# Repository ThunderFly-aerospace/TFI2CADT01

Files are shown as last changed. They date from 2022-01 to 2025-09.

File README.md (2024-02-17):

# TFI2CADT01 - I²C address translator

TFI2CADT01 is an I2C device address changer. This function allows you to connect multiple I2C devices with the same address to one master device on the same bus.

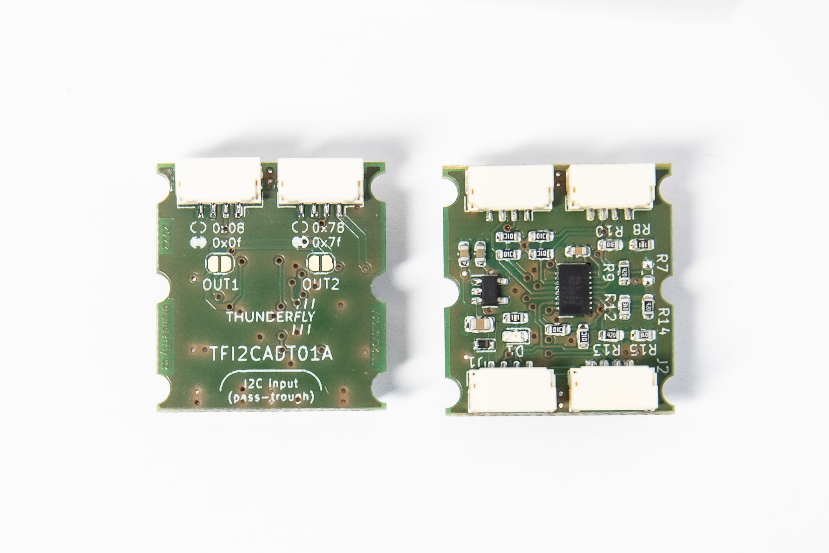
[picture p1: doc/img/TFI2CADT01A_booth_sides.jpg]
TFI2CADT01A PCB design


That is a common problem in case multiple I2C sensors with the same address (or a limited number of addresses) need to be connected to one I2C master. The purpose of this module is to change the address with which the I2C master calls to the address of the target I2C (slave) device.
The module is based on [LTC4317](https://www.analog.com/media/en/technical-documentation/data-sheets/4317fa.pdf) I2C address translator IC.
The module is designed and optimized for use on Pixhawk-compatible drones, especially UAVs. The design of the module is compatible with the [dronecode connectors standard](https://github.com/pixhawk/Pixhawk-Standards/blob/master/DS-009%20Pixhawk%20Connector%20Standard.pdf).

## Where to get it?

ThunderFly I2C address translator is commercially available from [ThunderFly s.r.o.](https://www.thunderfly.cz/), write an email to info@thunderfly.cz or shop at [Tindie store](https://www.tindie.com/products/thunderfly/tfi2cadt01-i2c-address-translator/).

## Translation function

The called address of the slave device is translated by a logical operation [XOR](https://en.wikipedia.org/wiki/Bitwise_operation#XOR) with the address bits configured in the TFI2CADT01 module. Each TFI2CADT01 port has a different default address. The address of each port can be changed independently by soldering solder jumpers JP1 and JP2.

NOTE: The TFI2CADT01 is not an I2C buffer, therefore the quality of input bits affects its function, and also corrupted data on input are propagated on the output. The address translator does XOR with the input address clocked in. To avoid related issues with bus data integrity we strongly recommend using ThunderFly's [TFCABI2C cables](https://github.com/ThunderFly-aerospace/TFCAB01) which minimizes SDA/SCL crosstalks. In some cases, where the I2C network has a significant length or number of nodes the use of [TFI2CEXT01](https://github.com/ThunderFly-aerospace/TFI2CEXT01), that is I2C extender with buffer function. 

## Configuration

The default address translation is listed in the following table.

| Port | Solder jumper | XOR value (in hex) | XOR value in binary form |
|---|---|---|---|
| 1 | Disconnected (default) | 0x08 | 0b0001000 |
| 1 | Soldered | 0x0f | 0b0001111 |
| 2 | Disconnected (default) | 0x78 | 0b1111000 |
| 2 | Soldered | 0x7f | 0b1111111 |

The connectors on the top side and the unpopulated connector on the bottom side are identical. There is no address difference between them. That should be used to split the bus to other sensors.

### Determining the new address of the I2C device

The new device address which should be called by the master could be calculated by doing XOR with the TFI2CADT01 port address and original device address.  The result is the new device address. You can use an [online calculator](https://xor.pw/) to do that. Another approach is determining the new address heuristically by use of the `i2cdetect` command or similar. 

## Example of usage

The TFI2CADT01 could be used with a wide variety of ThunderFly or Pixhawk I²C sensors, here are a few examples.

### Tachometer (RPM) sensors

The TFI2CADT01 could be easily used for the connection of multiple [TFRPM01 tachometer](https://github.com/ThunderFly-aerospace/TFRPM01) sensors, which is especially useful for multi-rotor airframes.

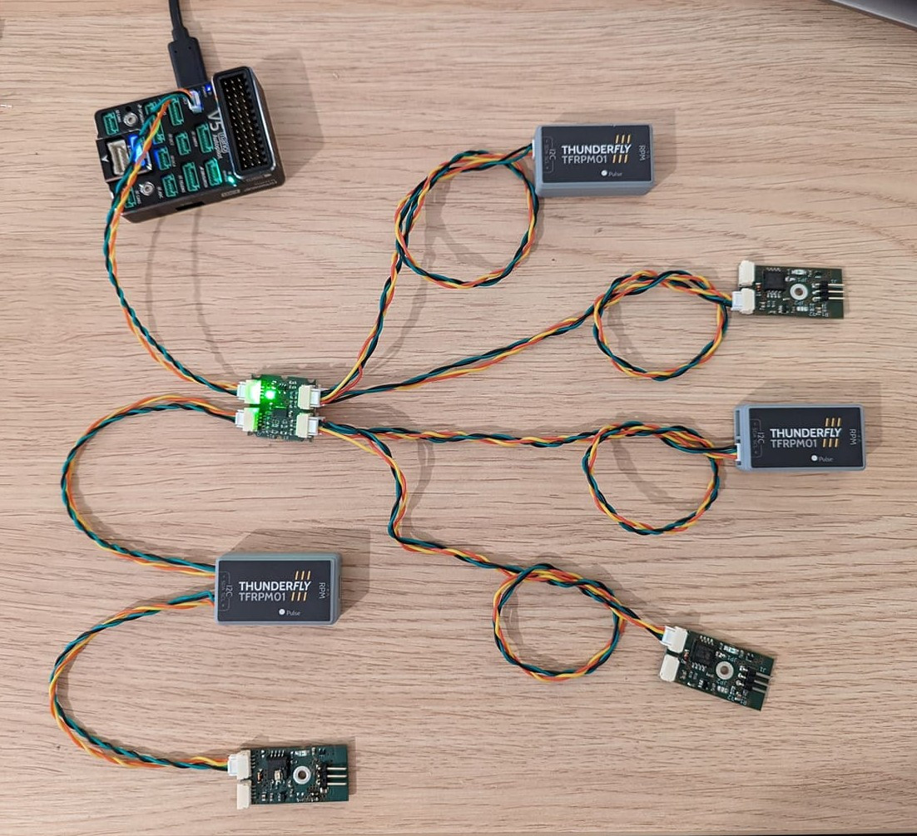
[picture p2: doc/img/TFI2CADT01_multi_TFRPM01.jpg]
TFI2CADT01A using multiple TFRPM01 sensors


### Redundant airspeed sensors

The TFI2CADT01 could also fix troubles with the connection of multiple [TFSLOT01 airspeed sensors](https://github.com/ThunderFly-aerospace/TFSLOT01) to one bus. It could be used even for other I2C-based airspeed sensors. That could increase the redundancy, in situations where a failure of the sensor is more probable than failure of the bus itself.

TFSLOT airspeed sensor

### Temperature and hygrometer sensors

For example the [TFHT01](https://github.com/ThunderFly-aerospace/TFHT01) connected by use of TFI2CADT01 allows measuring of temperature and humidity by multiple airframe locations at once.

TFHT01

## FAQ

### How I can change the I2C addresses used in the Pixhawk to the ones translated by the TFI2CADT01?

The translated addresses might not be recognized by default in the PX4 (that is usually experienced in the case of the SDP3x sensor driver).
One approach to solve that is to create a configuration file named `config.txt` on the SD card as is documented in the [PX4 documentation](https://docs.px4.io/main/en/concept/system_startup.html#replacing-the-system-startup). In this file, you can specify the start commands for the driver of the translated sensors.

Here's an example of the content of the `/etc/config.txt` on the SD card:

```
sdp3x_airspeed start -X -a <translated_address_a>
sdp3x_airspeed start -X -a <translated_address_b>
```

Replace `<translated_address_a>` and `<translated_address_b>` with the actual translated I2C addresses of your sensors. Addresses could be obtained by calculating XOR with the original address. Or it can be obtained with the `i2cdetect` command.

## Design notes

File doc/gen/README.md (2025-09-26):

# PCB

Board size: 25.0x23.0 mm (0.98x0.91 inches)

- This is the size of the rectangle that contains the board
- Thickness: 1.6 mm (63 mils)
- Material: FR4
- Finish: None
- Layers: 2
- Copper thickness: 35 µm

Solder mask: TOP / BOTTOM

- Color: Green

Silk screen: TOP / BOTTOM

- Color: White

Stackup:

| Name | Type | Color | Thickness [µm]| Material | Er | Loss tan |
|---|---|---|---|---|---|---|
| F.SilkS | Top Silk Screen | | | | | |
| F.Paste | Top Solder Paste | | | | | |
| F.Mask | Top Solder Mask | Green | 10 | | | |
| F.Cu | copper | | 35 | | | |
| dielectric 1 | core | | 1510 | FR4 | 4.5 | 0.020 |
| B.Cu | copper | | 35 | | | |
| B.Mask | Bottom Solder Mask | Green | 10 | | | |
| B.Paste | Bottom Solder Paste  | | | | | |
| B.SilkS | Bottom Silk Screen | | | | | |

# Important sizes

Clearance: 0.2 mm (8 mils)

Track width: 0.2 mm (8 mils)

- By design rules: 0.2 mm (8 mils)

Drill: 0.5 mm (20 mils)

- Vias: 0.5 mm (20 mils) [Design: 0.4 mm (16 mils)]
- Pads: 3.0 mm (118 mils)
- The above values are real drill sizes, they add 0.1 mm (4 mils) to plated holes (PTH)

Via: 0.8/0.4 mm (31/16 mils)

- By design rules: 0.4/0.3 mm (16/12 mils)
- Micro via: yes [0.2/0.1 mm (8/4 mils)]
- Buried/blind via: yes
- Total: 49 (thru: 49 buried/blind: 0 micro: 0)

Outer Annular Ring: 0.15 mm (6 mils)

- By design rules: N/A mm (N/A mils)

Eurocircuits class: 4B
- Using min drill 0.5 mm for an OAR of 0.15 mm

# General stats

Components count: (SMD/THT)

- Top: 2/6 (SMD + THT)
- Bottom: 27/0 (SMD)

Defined tracks:

- 0.2 mm (8 mils)
- 0.3 mm (12 mils)
- 0.4 mm (16 mils)
- 0.5 mm (20 mils)
- 0.6 mm (24 mils)

Used tracks:

- 0.2 mm (8 mils) (155) defined: yes
- 0.25 mm (10 mils) (20) defined: no
- 0.5 mm (20 mils) (73) defined: yes

Defined vias:

Used vias:

- 0.8/0.4 mm (31/16 mils) (Count: 49, Aspect: 2.0 A) defined: no

Holes (excluding vias):

- 3.0 mm (118 mils) (6)

Oval holes:

Drill tools (including vias and computing adjusts and rounding):

- 0.5 mm (20 mils) (49)
- 3.0 mm (118 mils) (6)

Solder paste stats:

Using a paste with 87.75 % alloy, that has an specific gravity for the alloy of 7.4 g/cm³
and 1.0 g/cm³ for the flux. This paste has an specific gravity of  4.15 g/cm³.

The stencil thickness is  0.12 mm.

| Side | Pads with paste | Area [mm²] | Paste [g] |
|---|---|---|---|
| Top | 12 | 18.56 | 0.09 |
| Bottom | 97 | 80.05 | 0.40 |
| Total  | 109 | 98.61 | 0.49 |

Note: this is just an approximation to the theoretical value. Margins of the solder mask and waste aren't computed.

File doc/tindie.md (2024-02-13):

### What is it?
TFI2CADT is a device translating addresses of I2C devices on a bus. As a result, multiple I2C slave devices with the same address can be connected to one master device. One TFI2CADT01 allows connecting 3 identical I2C devices (with one address) to one bus. The I2C slave device will be visible under three addresses. 

The module is designed in accordance with the [pixhawk connector dronecode](https://github.com/pixhawk/Pixhawk-Standards/blob/master/DS-009%20Pixhawk%20Connector%20Standard.pdf) standard. Thanks to this, it can be very easily implemented into the existing avionics of your drone.

### Why did we make it?
It often happens that more identical I2C devices (with the same address) need to be connected to one bus. We even had a request for connecting 4-8 RPM tachometers [TFRPM01](https://www.tindie.com/products/thunderfly/tfrpm01-drone-rpm-tachometer-sensor/) to PX4 autopilot.

### What makes it special?
The device is unique in that the address translation takes place in real-time, during communication via I2C. The user software does not have to deal with any multiplexer channels switching or disconnecting individual parts of the bus. This feature also solves the amount of data flow on the bus. All devices are constantly visible for the I2C master device.

###  How does the translation work?
The address translation takes place internally. A logical operation XOR with a preset value is applied to the address sent by the master. The XOR value is different for each channel. 

By default, an XOR value of 0x08 is applied on the first port and a value of 0x78 on the second port. These values can be easily changed to 0x0f and 0x7f respectively, by short-circuiting the solder jumper.

If these changes are still not sufficient, using configuration resistors you can create any XOR translation of the original address of the device. More information about the address change can be found in the datasheet.

###  How do I connect with the translator? 
Connecting the translator is simple. It is just placed between the I2C master and I2C slave devices. TFI2CADT has JST-GH connectors whose connection corresponds to the dronecode standard. 

Using an adequate cable, the translator can be connected to e.g. Arduino, raspberry, or other devices using I2C. The board is equipped with a pair of input ports that are internally interconnected to enable daisy-chain topology.

### How is the translator supported? 

The translator does not need a software configuration and from the point of view of I2C communication is not visible. Thanks to this, it can be used with any I2C bus, therefore it could be used with any Pixhawk autopilot compatible firmware like [PX4](https://px4.io/) or [Ardupilot](https://ardupilot.org/) additionally the usage is not limited to UAVs only.

### What’s included?

- 1x TFI2CADT01B
- Optionally: 
   - [TFCABxxI2C01](https://github.com/ThunderFly-aerospace/TFCAB01) Silicone I2C cable with JST-GH connectors

### Accessories

#### I2C cabling 
Additional I2C cables for connecting to the autopilot are not included in the package. You must purchase the additional cables separately from our [tindie catalog](https://www.tindie.com/stores/thunderfly/). We offer high-quality cables that are compatible with the [Pixhawk standard](https://raw.githubusercontent.com/pixhawk/Pixhawk-Standards/master/DS-009%20Pixhawk%20Connector%20Standard.pdf) and with a [ThunderFly color](https://docs.px4.io/main/en/assembly/cable_wiring.html#i2c-cables) scheme for easy signal identification. Our cables are specifically designed with improved resistance to electromagnetic interference and a silicone insulator that makes them highly flexible.

  * [TFCABxxI2C01 products](https://www.tindie.com/products/30113/)

# Product changelog
The product is gradually evolving and improving based on user requirements. Currently (as of 02/2024), the TFI2CADT01B revision is being shipped. In the development process, we keep backward compatibility, for example by keeping the same form factor or communication interface. The complete list of changes is in [releases](https://github.com/ThunderFly-aerospace/TFI2CADT01/releases).
 
#### TFI2CADT01B - (from 2/2024)
 * JST-GH connectors moved slightly into the PCB contour to enhance the protection of the connector and improve soldering quality.

#### TFI2CADT01A - initial version

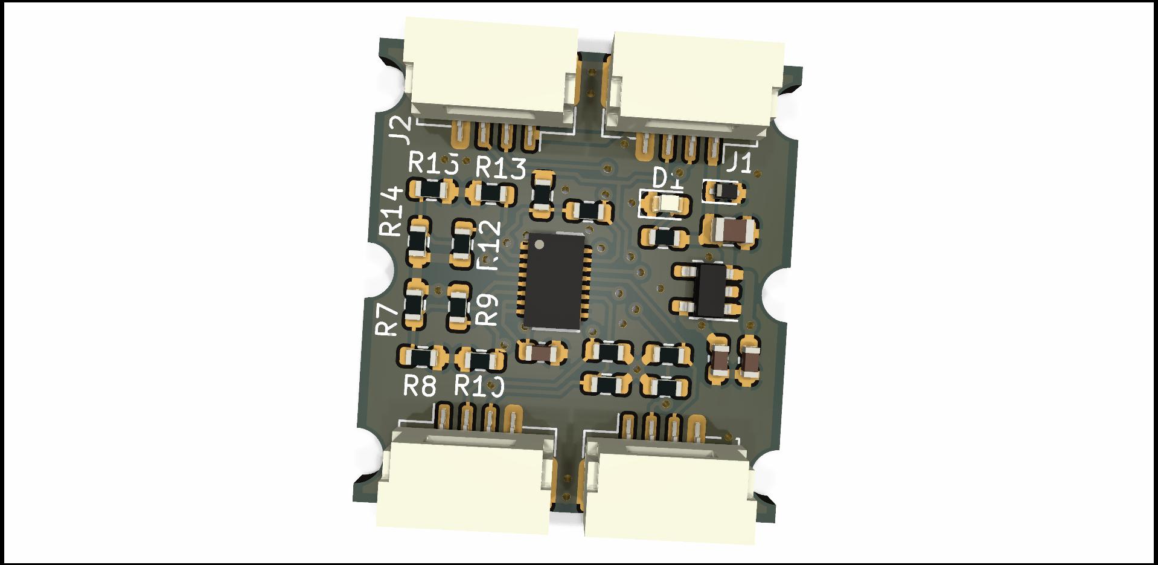
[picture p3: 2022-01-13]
doc/img/TFI2CADT01A_big_bot.jpg

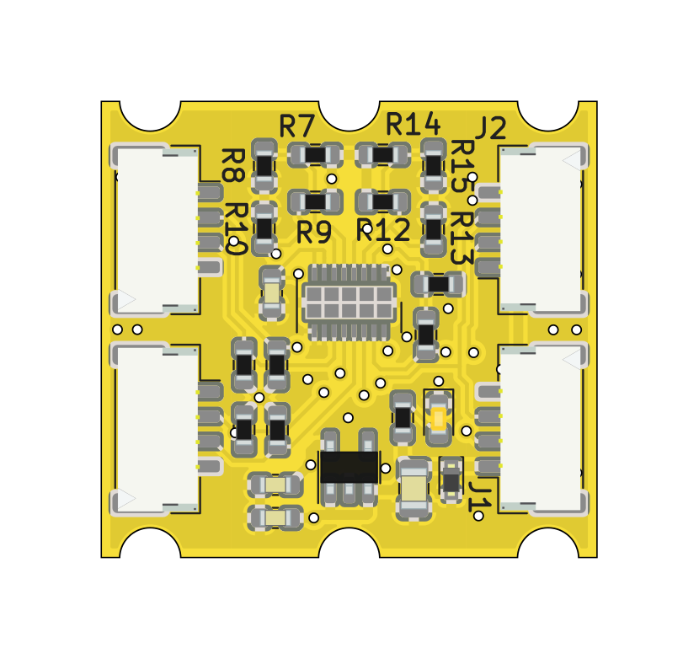
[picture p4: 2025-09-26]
doc/gen/img/TFI2CADT01-bottom.png

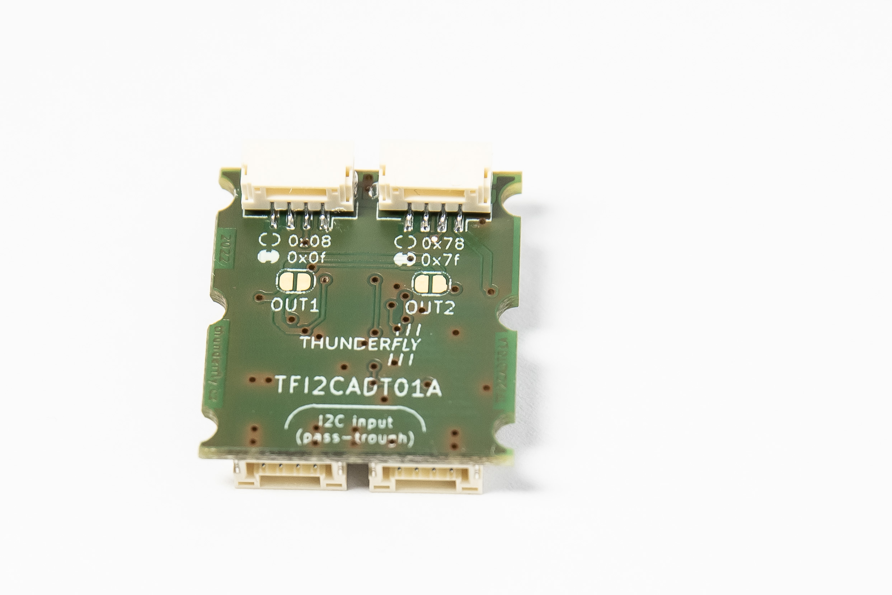
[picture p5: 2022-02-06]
doc/img/TFI2CADT01A_img.jpg

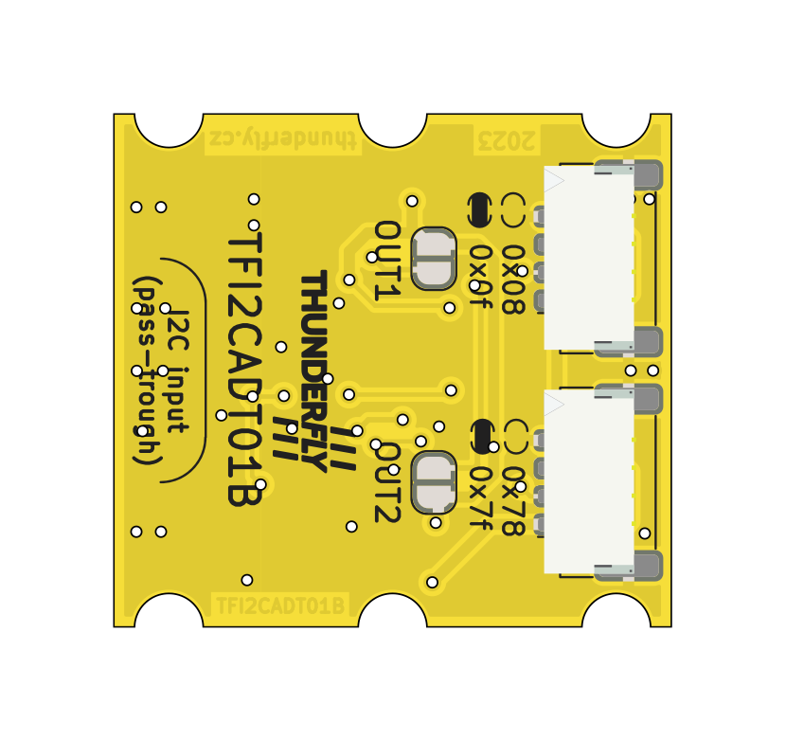
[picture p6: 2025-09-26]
doc/gen/img/TFI2CADT01-top.png

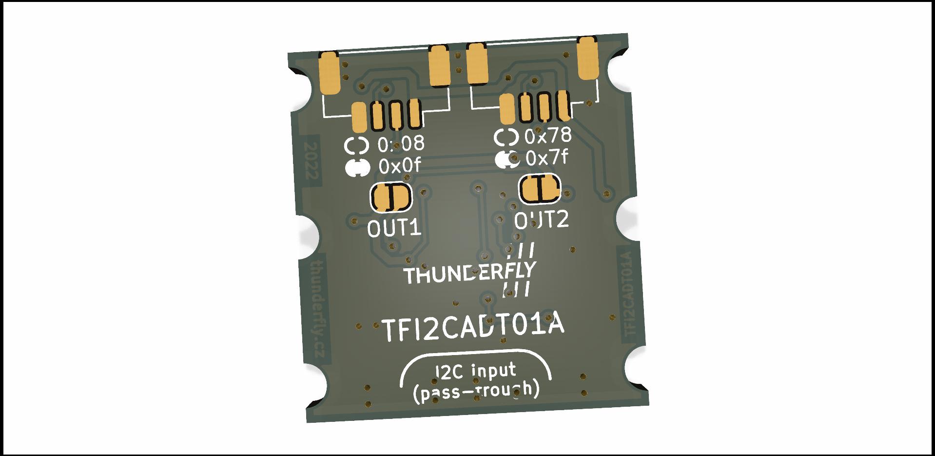
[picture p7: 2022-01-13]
doc/img/TFI2CADT01A_big_top.jpg

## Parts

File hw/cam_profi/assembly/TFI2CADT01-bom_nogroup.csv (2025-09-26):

Component | Description | Part | References | Value | Footprint | Quantity Per PCB | Datasheet | ust_id
1 | Unpolarized capacitor | C | C2 | 100nF | C_0603_1608Metric | 1 | ~ | 5c70984812875079b91f8bf2
2 | Unpolarized capacitor | C | C4 | 100nF | C_0603_1608Metric | 1 | ~ | 5c70984812875079b91f8bf2
3 | Unpolarized capacitor | C | C3 | 1uF | C_0603_1608Metric | 1 | ~ | 5c70984812875079b91f8bc2
4 | Unpolarized capacitor | C | C1 | 10uF | C_0805_2012Metric | 1 | ~ | 5c70984812875079b91f8bbd
5 |  | D_ZENER | D2 | BZX585-B5V6.115 | D_SOD-523 | 1 |  | 60879d38128750769ee58e48
6 | Light emitting diode | LED | D1 | LED GREEN | LED_0603_1608Metric | 1 | ~ | 60d582331287500165f859d0
7 |  | SM04B-GHS-TB | J1 | SM04B-GHS-TB | JST_GH_SM04B-GHS-TB_1x04-1MP_P1.25mm_Horizontal | 1 |  | 5c86273d1287500b4e0280be
8 |  | SM04B-GHS-TB | J2 | SM04B-GHS-TB | JST_GH_SM04B-GHS-TB_1x04-1MP_P1.25mm_Horizontal | 1 |  | 5c86273d1287500b4e0280be
9 |  | SM04B-GHS-TB | J3 | SM04B-GHS-TB | JST_GH_SM04B-GHS-TB_1x04-1MP_P1.25mm_Horizontal | 1 |  | 5c86273d1287500b4e0280be
10 |  | SM04B-GHS-TB | J4 | SM04B-GHS-TB | JST_GH_SM04B-GHS-TB_1x04-1MP_P1.25mm_Horizontal | 1 |  | 5c86273d1287500b4e0280be
11 |  | SM04B-GHS-TB | J5 | SM04B-GHS-TB | JST_GH_SM04B-GHS-TB_1x04-1MP_P1.25mm_Horizontal | 1 |  | 5c86273d1287500b4e0280be
12 |  | SM04B-GHS-TB | J6 | SM04B-GHS-TB | JST_GH_SM04B-GHS-TB_1x04-1MP_P1.25mm_Horizontal | 1 |  | 5c86273d1287500b4e0280be
13 | Resistor | R | R1 | 180R | R_0603_1608Metric | 1 | ~ | 5c70984512875079b91f8957
14 | Resistor | R | R8 | 180R | R_0603_1608Metric | 1 | ~ | 5c70984512875079b91f8957
15 | Resistor | R | R16 | 10k | R_0603_1608Metric | 1 | ~ | 5c70984512875079b91f8962
16 | Resistor | R | R17 | 10k | R_0603_1608Metric | 1 | ~ | 5c70984512875079b91f8962
17 | Resistor | R | R2 | 10k | R_0603_1608Metric | 1 | ~ | 5c70984512875079b91f8962
18 | Resistor | R | R3 | 10k | R_0603_1608Metric | 1 | ~ | 5c70984512875079b91f8962
19 | Resistor | R | R5 | 10k | R_0603_1608Metric | 1 | ~ | 5c70984512875079b91f8962
20 | Resistor | R | R6 | 10k | R_0603_1608Metric | 1 | ~ | 5c70984512875079b91f8962
21 | Resistor | R | R13 | 887k | R_0603_1608Metric | 1 | ~ | 6272c899dc56076e9a222bfe
22 | Resistor | R | R14 | 887k | R_0603_1608Metric | 1 | ~ | 6272c899dc56076e9a222bfe
23 | Resistor | R | R9 | 887k | R_0603_1608Metric | 1 | ~ | 6272c899dc56076e9a222bfe
24 | Resistor | R | R10 | 1M | R_0603_1608Metric | 1 | ~ | 61e030ee2eac0c9aef5c8995
25 | Resistor | R | R12 | 1M | R_0603_1608Metric | 1 | ~ | 61e030ee2eac0c9aef5c8995
26 | Resistor | R | R15 | 1M | R_0603_1608Metric | 1 | ~ | 61e030ee2eac0c9aef5c8995
27 | Resistor | R | R7 | - | R_0603_1608Metric | 1 | ~
28 | Dual I2C/SMBus Address-Translator, DFN-16 | LTC4317 | U2 | LTC4317 | DFN-16-1EP_3x5mm_P0.5mm_EP1.66x4.4mm | 1 | https://www.analog.com/media/en/technical-documentation/data-sheets/4317fa.pdf | 61e031592eac0c9aef5c89ad
29 | 300mA Low-dropout Voltage Regulator, Vout 3.3V, Vin up to 5.5V, SOT-23 | MIC5504-3.3YM5 | U1 | MIC5504-3.3YM5 | SOT-23-5 | 1 | http://ww1.microchip.com/downloads/en/DeviceDoc/MIC550X.pdf | 5c7255e81287500b4e112ea2

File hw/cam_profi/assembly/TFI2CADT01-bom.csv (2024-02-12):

Row | Description | Part | References | Value | Footprint | Quantity Per PCB | Status | Datasheet | UST_id
1 | Unpolarized capacitor | C | C2 C4 | 100nF | C_0603_1608Metric | 2 |  |  | 5c70984812875079b91f8bf2
2 | Unpolarized capacitor | C | C3 | 1uF | C_0603_1608Metric | 1 |  |  | 5c70984812875079b91f8bc2
3 | Unpolarized capacitor | C | C1 | 10uF | C_0805_2012Metric | 1 |  |  | 5c70984812875079b91f8bbd
4 |  | D_ZENER | D2 | BZX585-B5V6.115 | D_SOD-523 | 1 |  |  | 60879d38128750769ee58e48
5 | Light emitting diode | LED | D1 | LED GREEN | LED_0603_1608Metric | 1 |  |  | 60d582331287500165f859d0
6 |  | SM04B-GHS-TB | J1 J2 J3 J4 J5 J6 | SM04B-GHS-TB | JST_GH_SM04B-GHS-TB_1x04-1MP_P1.25mm_Horizontal | 6 |  |  | 5c86273d1287500b4e0280be
7 | Resistor | R | R1 R8 | 180R | R_0603_1608Metric | 2 |  |  | 5c70984512875079b91f8957
8 | Resistor | R | R2 R3 R5 R6 R16 R17 | 10k | R_0603_1608Metric | 6 |  |  | 5c70984512875079b91f8962
9 | Resistor | R | R9 R13 R14 | 887k | R_0603_1608Metric | 3 |  |  | 6272c899dc56076e9a222bfe
10 | Resistor | R | R10 R12 R15 | 1M | R_0603_1608Metric | 3 |  |  | 61e030ee2eac0c9aef5c8995
11 | Resistor | R | R7 | - | R_0603_1608Metric | 1
12 | Dual I2C/SMBus Address-Translator, DFN-16 | LTC4317 | U2 | LTC4317 | DFN-16-1EP_3x5mm_P0.5mm_EP1.66x4.4mm | 1 |  | https://www.analog.com/media/en/technical-documentation/data-sheets/4317fa.pdf | 61e031592eac0c9aef5c89ad
13 | 300mA Low-dropout Voltage Regulator, Vout 3.3V, Vin up to 5.5V, SOT-23 | MIC5504-3.3YM5 | U1 | MIC5504-3.3YM5 | SOT-23-5 | 1 |  | http://ww1.microchip.com/downloads/en/DeviceDoc/MIC550X.pdf | 5c7255e81287500b4e112ea2
Project info:
Schematic: | TFI2CADT01
Variant: | default
Revision:
Date: | 2021-04-05
KiCad Version: | 7.0.10-7.0.10~ubuntu23.04.1
Statistics:
Component Groups: | 13
Component Count: | 29
Fitted Components: | 29
Number of PCBs: | 1
Total Components: | 29

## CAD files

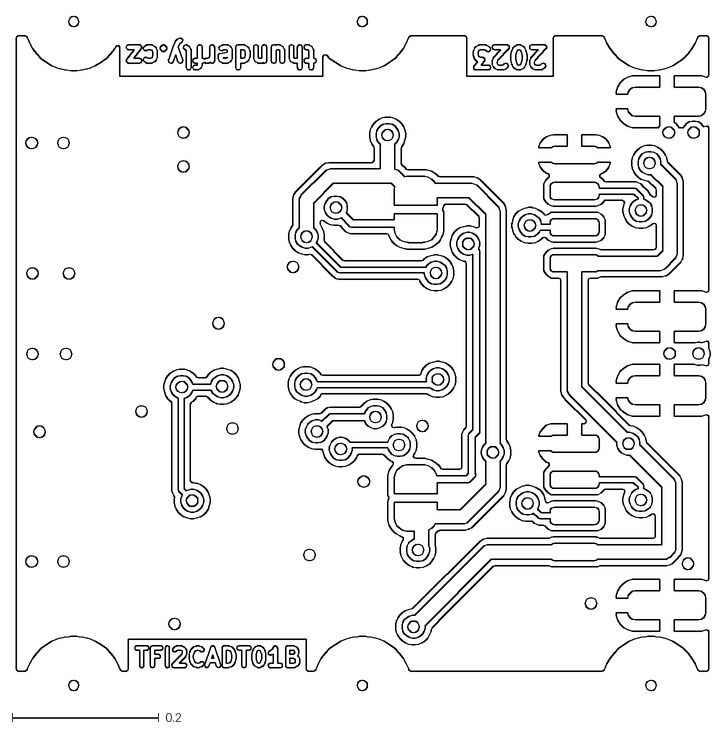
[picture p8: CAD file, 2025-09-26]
doc/gen/dxf/TFI2CADT01-F_Cu.dxf
0.947 x 0.919

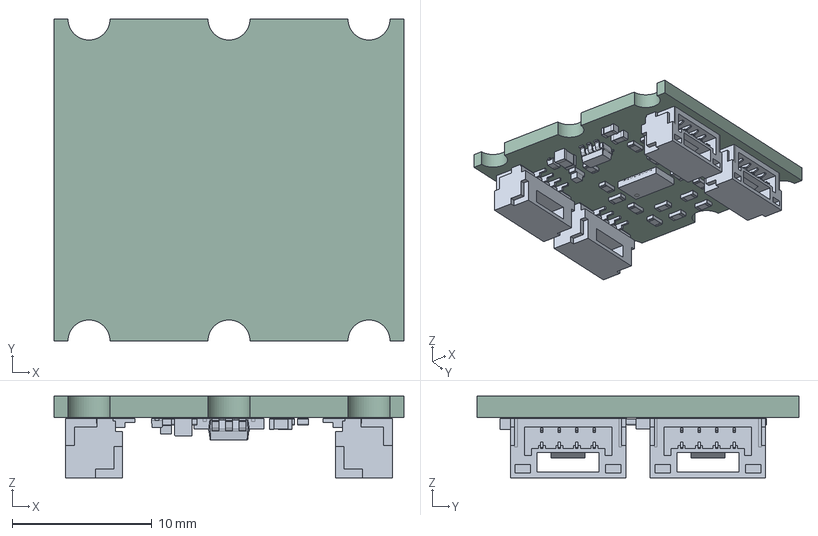
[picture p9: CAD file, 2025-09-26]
doc/gen/TFI2CADT01.step
25.0 x 23.0 x 5.84 mm
R_0603_1608Metric x 15
LED_0603_1608Metric
C_0603_1608Metric x 3
D_SOD-523
JST_GH_SM04B-GHS-TB_1x04-1MP_P1.25mm_Horizontal x 4
SOT-23-5
DFN-16-1EP_3x5mm_P0.5mm_EP1.66x4.4mm
C_0805_2012Metric
kibot_f15ytz6k_PCB

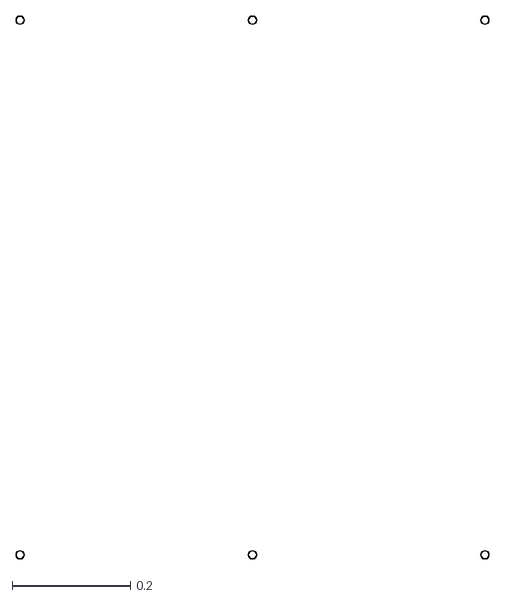
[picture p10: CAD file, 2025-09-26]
doc/gen/dxf/TFI2CADT01-Margin.dxf
0.801 x 0.919

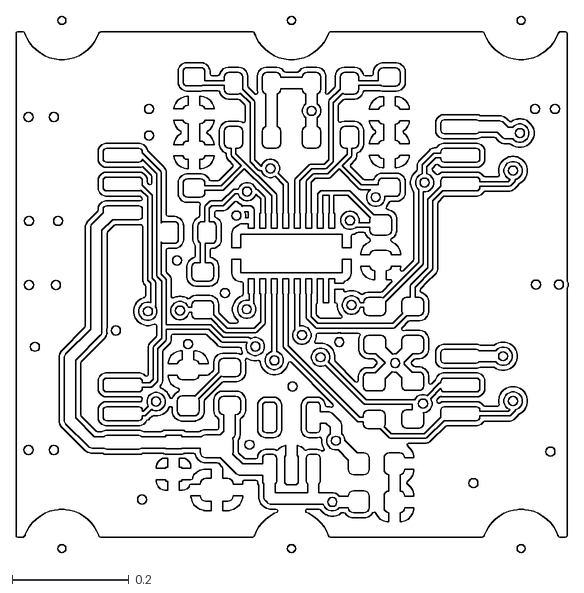
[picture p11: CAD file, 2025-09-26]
doc/gen/dxf/TFI2CADT01-B_Cu.dxf
0.947 x 0.919

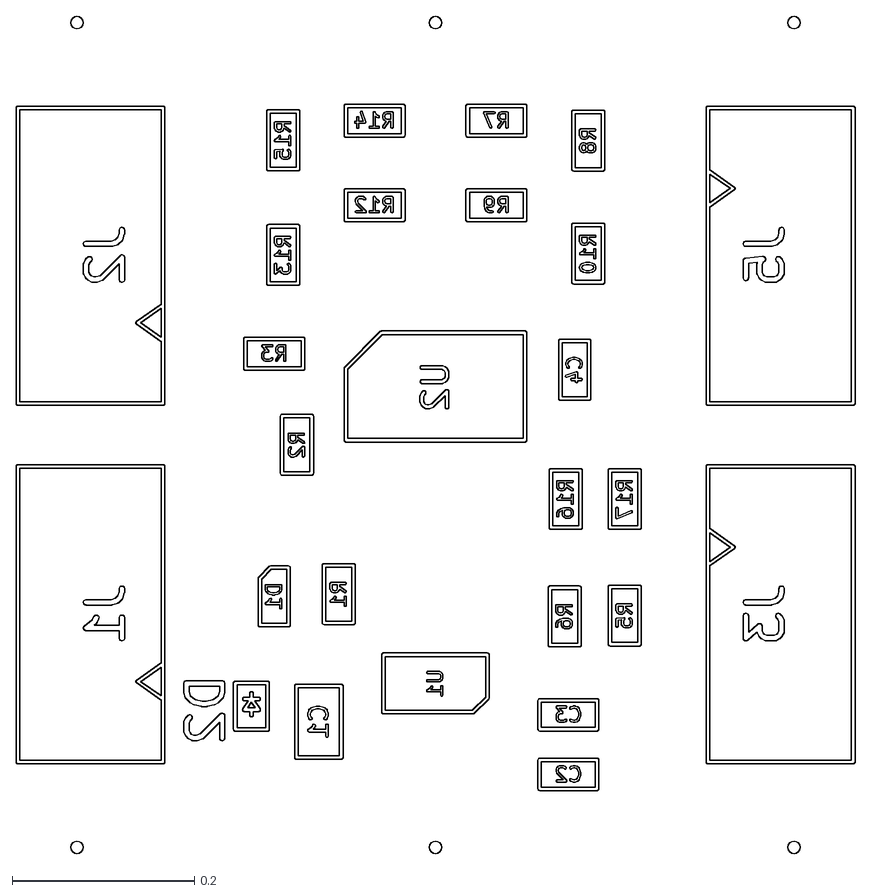
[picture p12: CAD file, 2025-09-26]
doc/gen/dxf/TFI2CADT01-B_Fab.dxf
0.921 x 0.919

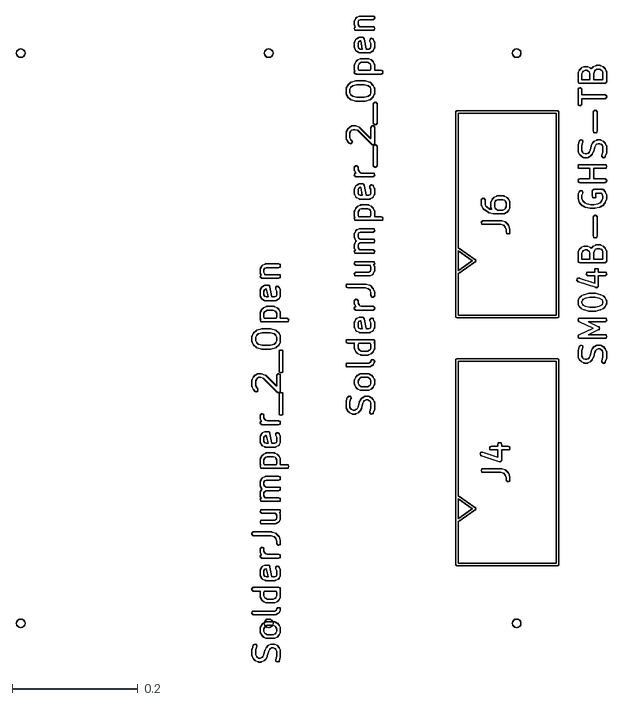
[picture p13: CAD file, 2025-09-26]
doc/gen/dxf/TFI2CADT01-F_Fab.dxf
0.937 x 1.03

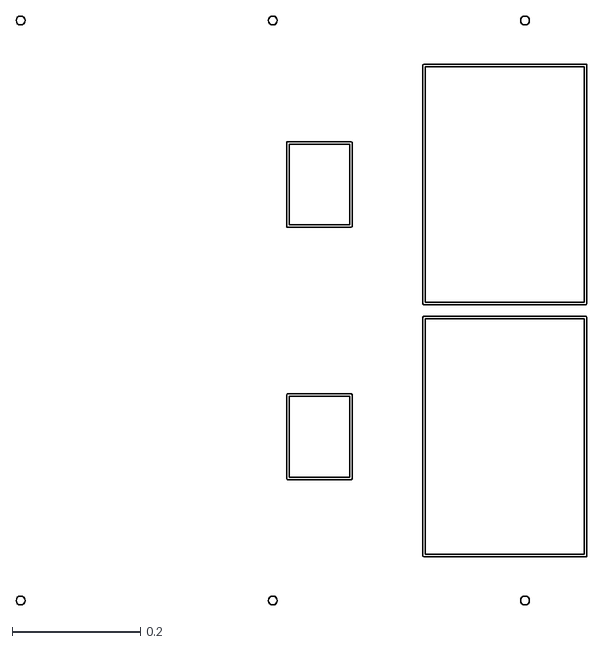
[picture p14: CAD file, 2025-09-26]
doc/gen/dxf/TFI2CADT01-F_Courtyard.dxf
0.891 x 0.919

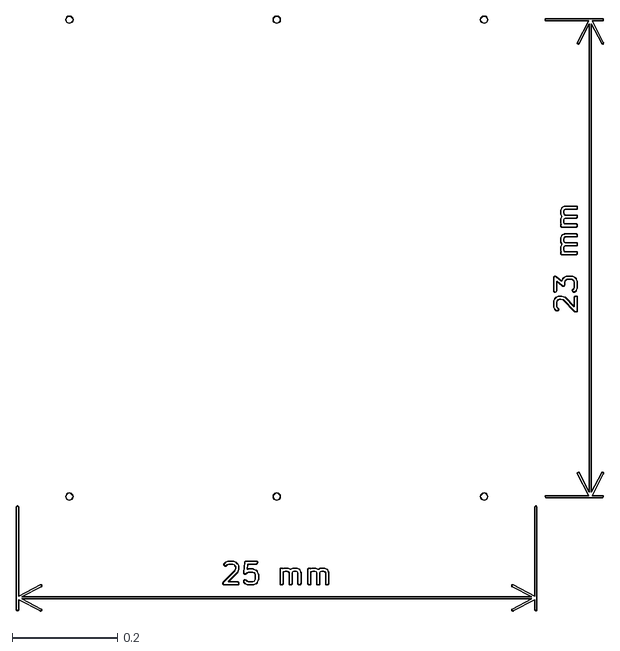
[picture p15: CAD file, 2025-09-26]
doc/gen/dxf/TFI2CADT01-User_Drawings.dxf
1.11 x 1.13

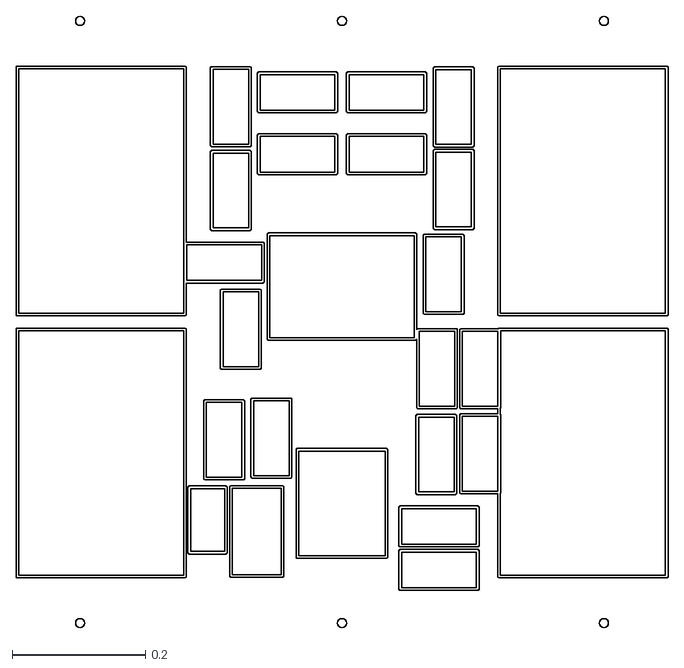
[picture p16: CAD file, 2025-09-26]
doc/gen/dxf/TFI2CADT01-B_Courtyard.dxf
0.98 x 0.919

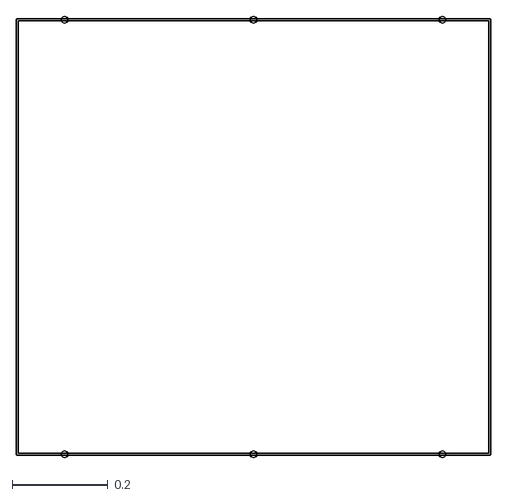
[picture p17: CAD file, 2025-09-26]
doc/gen/dxf/TFI2CADT01-Edge_Cuts.dxf
0.988 x 0.919

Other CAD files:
doc/gen/dxf/TFI2CADT01-B_Mask.dxf
doc/gen/dxf/TFI2CADT01-B_Paste.dxf
doc/gen/dxf/TFI2CADT01-B_Silkscreen.dxf
doc/gen/dxf/TFI2CADT01-F_Mask.dxf
doc/gen/dxf/TFI2CADT01-F_Paste.dxf
doc/gen/dxf/TFI2CADT01-F_Silkscreen.dxf

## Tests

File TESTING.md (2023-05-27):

# Testování TFI2CADT01

## Automatické testování (doporučeno)
Postup pro automatické testování sám zkontroluje přeloženou adresu I2C zařizení a vyhodnotí, jestli je to správně nebo ne. Jedná se o jupyter notebook, který je nutné spustit lokálně v počítači, který má prístup k SMBUS sběrnici z kernelu. Instrukce a návod k použití je vepsán přímo v notebooku. Test vyžaduje jedno další I2C zařízení (které obsahuje jedinou I2C adresu)

Notebook se nachází v [sw/pymlab/TFI2CADT_TEST.ipynb](sw/pymlab/TFI2CADT_TEST.ipynb)


## Základní (manuální) testování
Základní testování TFI2CADT01 po výrobě lze provést v kompinaci s TFRPM01 pomocí python [skriptu](https://github.com/ThunderFly-aerospace/TFRPM01/blob/TFRPM01C/sw/pymlab/TFRPM_readout.py) postaveném na knihovně [PyMLAB](https://github.com/MLAB-project/pymlab). 

Skript ze složky `/sw/pymlab/` spustíte příkazem:

```
sudo python3 TFRPM_readout.py 0 0x25
sudo python3 TFRPM_readout.py 0 0x58
```

Po úspěšném spuštění by se měly objevit měřené hodnoty. Nyní, pomocí nějaké sondy nebo uzeměním signálového pinu, simulujte čitací signál. Hodnota `count` by měla růst. Pro přesnější měření lze použit signál generovaný osciloskopem nebo jiným zdrojem pilového signálu. 

Výstup pak může vypadat následovně: 

```bash
TFRPM01 test suite.
{'port': '0', 'device': None, 'serial_number': None}
counter module example 

1608153501.8307571; count: 0, freq: 0.00, integration_time: 0.03
1608153502.3609016; count: 0, freq: 0.00, integration_time: 0.56
1608153502.8917809; count: 0, freq: 0.00, integration_time: 1.09
1608153503.4219267; count: 0, freq: 0.00, integration_time: 1.62
1608153503.9529395; count: 0, freq: 0.00, integration_time: 2.15
1608153504.4839747; count: 0, freq: 0.00, integration_time: 2.68
1608153505.0149646; count: 0, freq: 0.00, integration_time: 3.21
1608153505.5448906; count: 0, freq: 0.00, integration_time: 3.74
1608153506.0749886; count: 0, freq: 0.00, integration_time: 4.27
1608153506.6050436; count: 0, freq: 0.00, integration_time: 4.80
1608153507.136024; count: 0, freq: 0.00, integration_time: 5.34
1608153507.6670556; count: 0, freq: 0.00, integration_time: 5.87
1608153508.197005; count: 0, freq: 0.00, integration_time: 6.40
1608153508.728068; count: 0, freq: 0.00, integration_time: 6.93
1608153509.2590628; count: 2, freq: 0.27, integration_time: 7.46
1608153509.7890441; count: 5, freq: 0.63, integration_time: 7.99
1608153510.3190136; count: 8, freq: 0.94, integration_time: 8.52
1608153510.8490016; count: 11, freq: 1.22, integration_time: 9.05
1608153511.3801253; count: 14, freq: 1.46, integration_time: 9.58
```

V prvním sloupci je čas. Následuje počet detekovaných signálů, určená frekvence a čas po kterou je frekvence počitána.

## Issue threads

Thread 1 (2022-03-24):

PCB Dimensions

kaklik, 2022-03-24:
Díval jsem se teď na návrh PCB a překvapil mě tam rozměr. 23x25 mm. Není mi moc jasné, jak se k takovým rozměrům došlo. V posledním zápisu TFPCB je definováno takto:

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

Očekával bych tak šířku buď 24mm nebo 25mm ale 23mm je celkem překvapením.

roman-dvorak, 2022-03-24:
K tomu se došlo tak, že pokud by na PCB měly být všechny konektory (co tam jsou) a mělo by to splňovat všechny tyto podmínky, tak by to byla hodně/zbytečně velká deska. Možná 30x20, 30x25..

Zároveň se neuvažovalo o krabičkování v standartní (neexistující) krabičce pro tento pattern.

A tento modul má nepředpokládá montáž do míst, kam se montují senzory.

Připadá mi to zde úplně korektní.

Closed 2022-10-16.

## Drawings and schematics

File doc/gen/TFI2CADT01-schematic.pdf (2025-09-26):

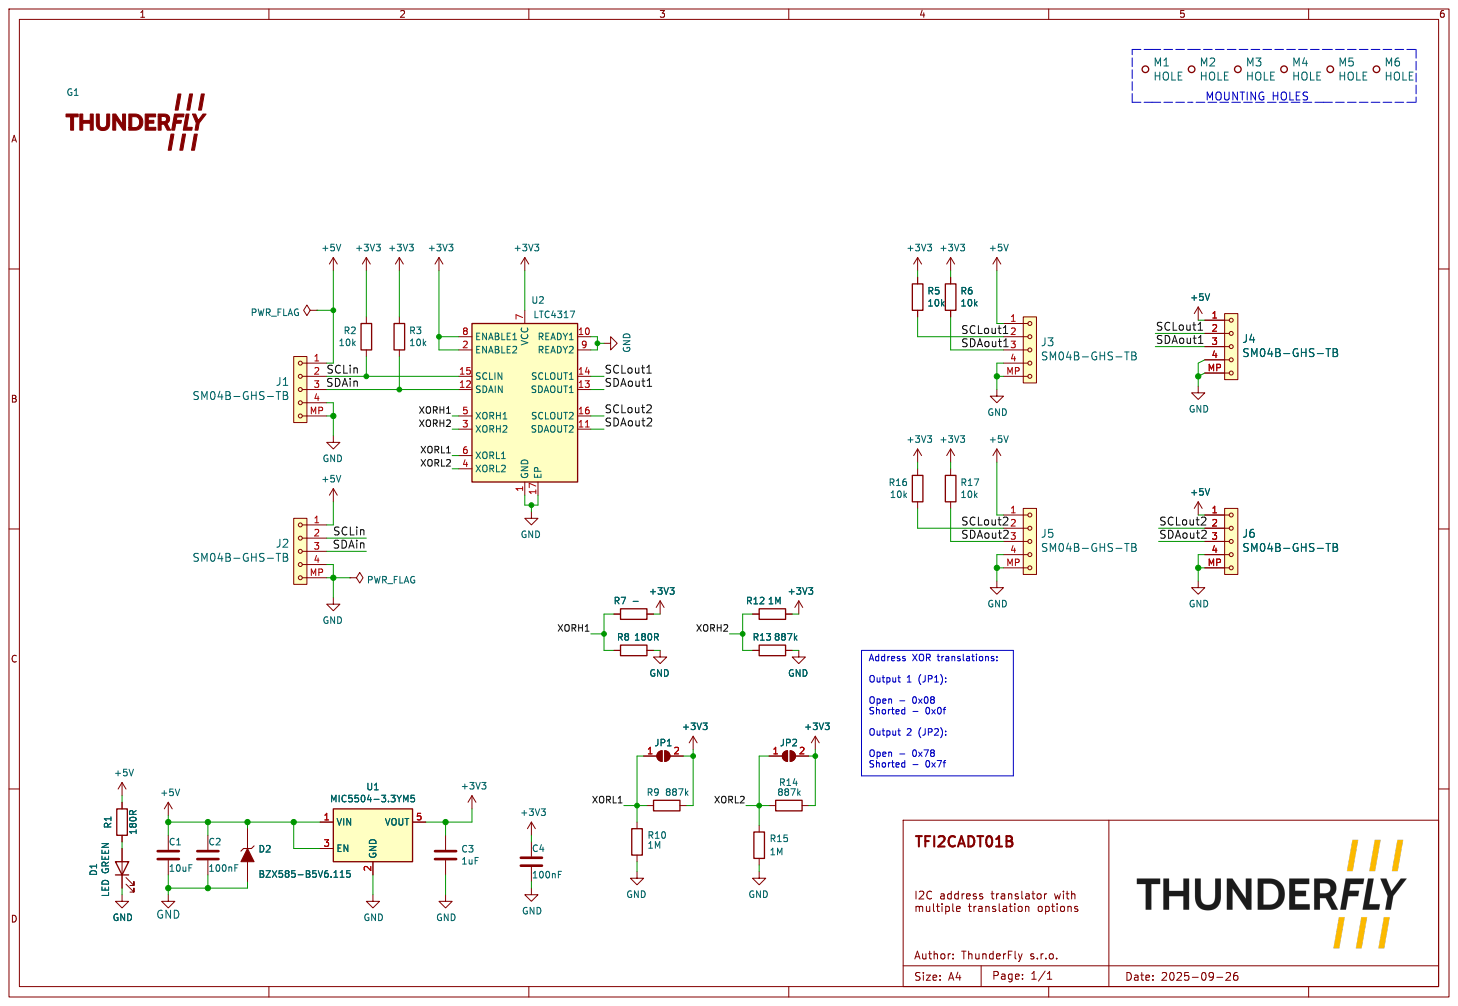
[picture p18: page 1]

J4SM04B-GHS-TB M3 HOLE M1 HOLE

2 VOUT 5 U1 MIC5504-3.3YM5 GND GND GND

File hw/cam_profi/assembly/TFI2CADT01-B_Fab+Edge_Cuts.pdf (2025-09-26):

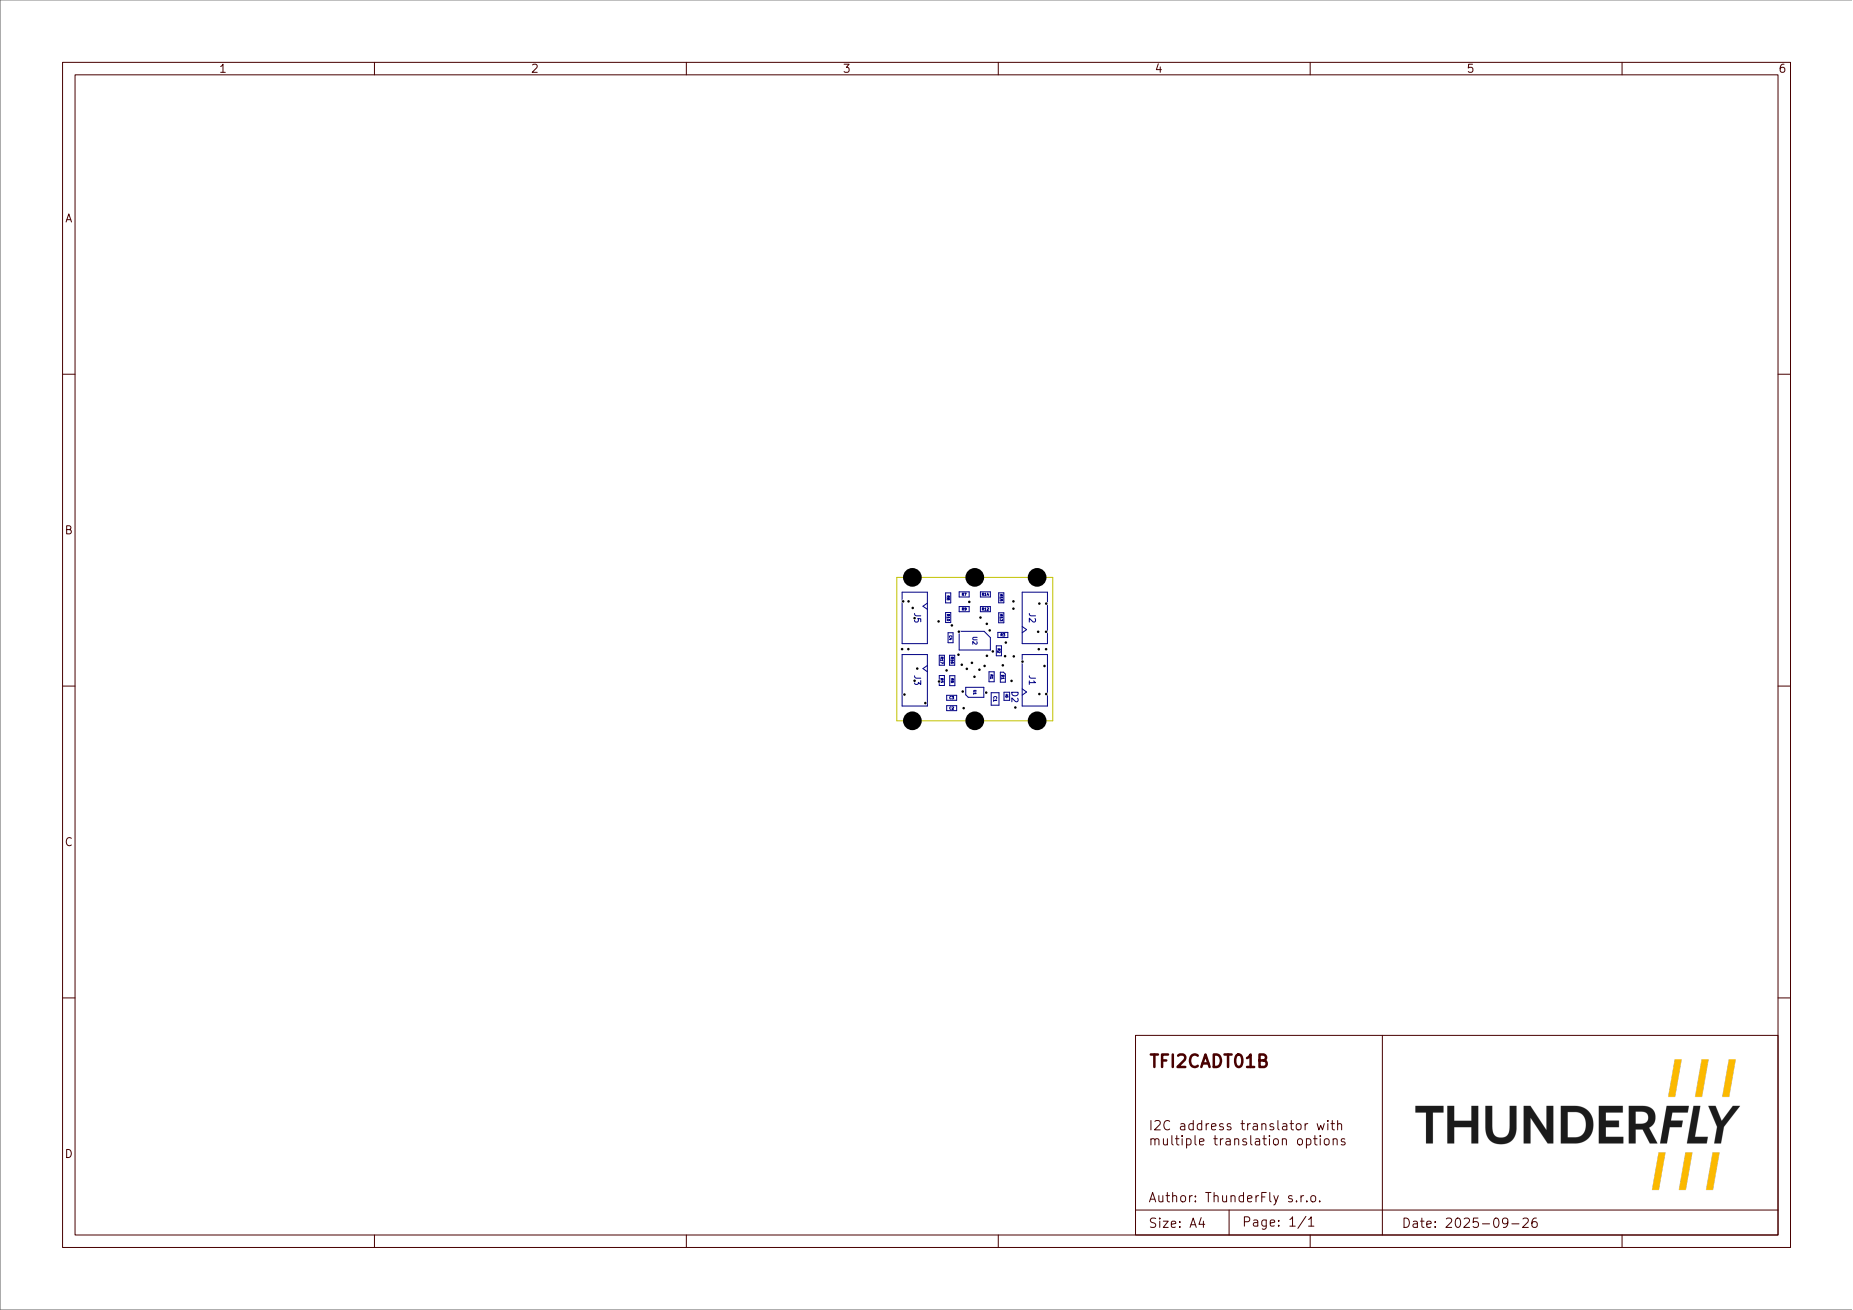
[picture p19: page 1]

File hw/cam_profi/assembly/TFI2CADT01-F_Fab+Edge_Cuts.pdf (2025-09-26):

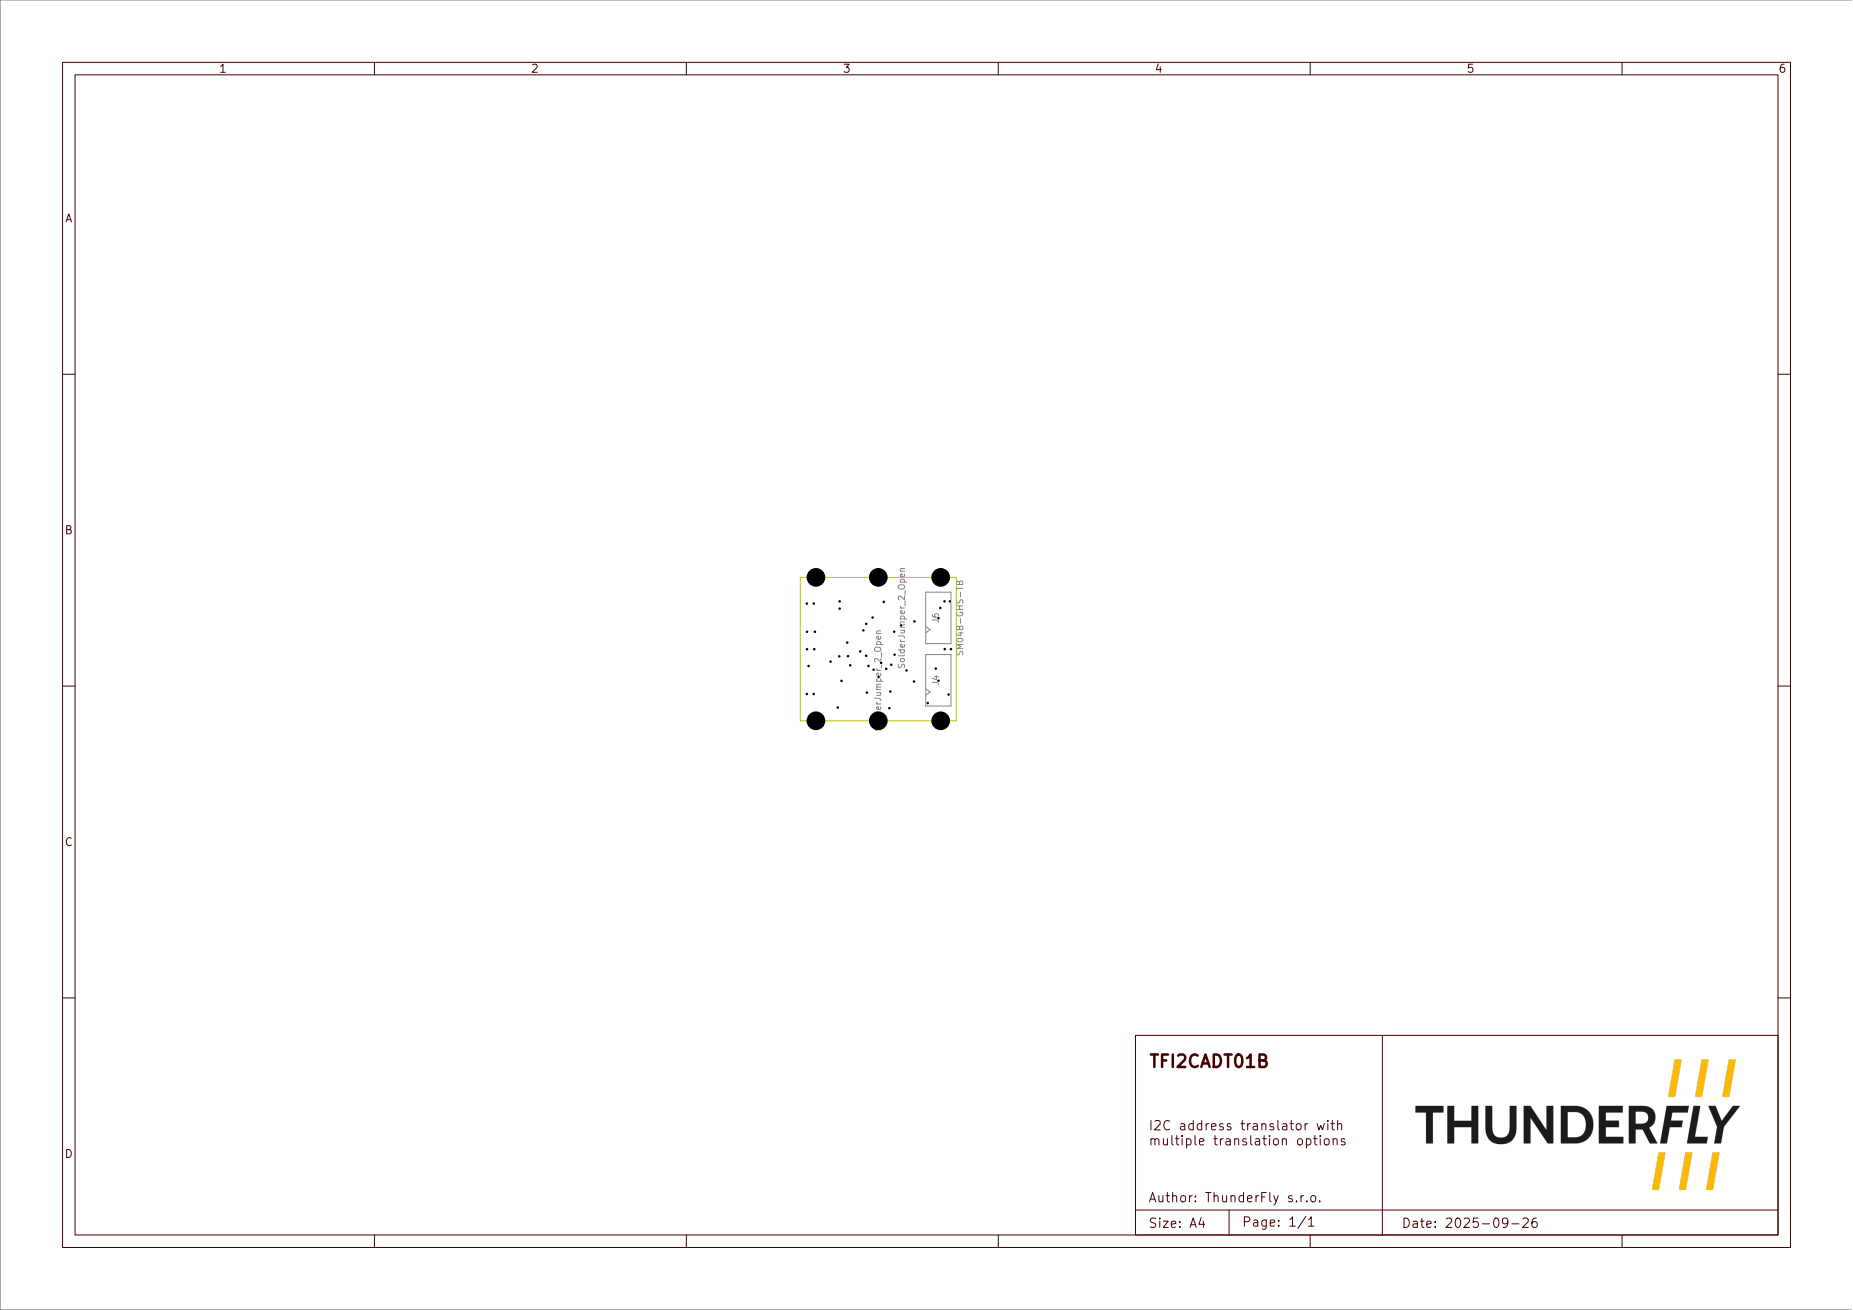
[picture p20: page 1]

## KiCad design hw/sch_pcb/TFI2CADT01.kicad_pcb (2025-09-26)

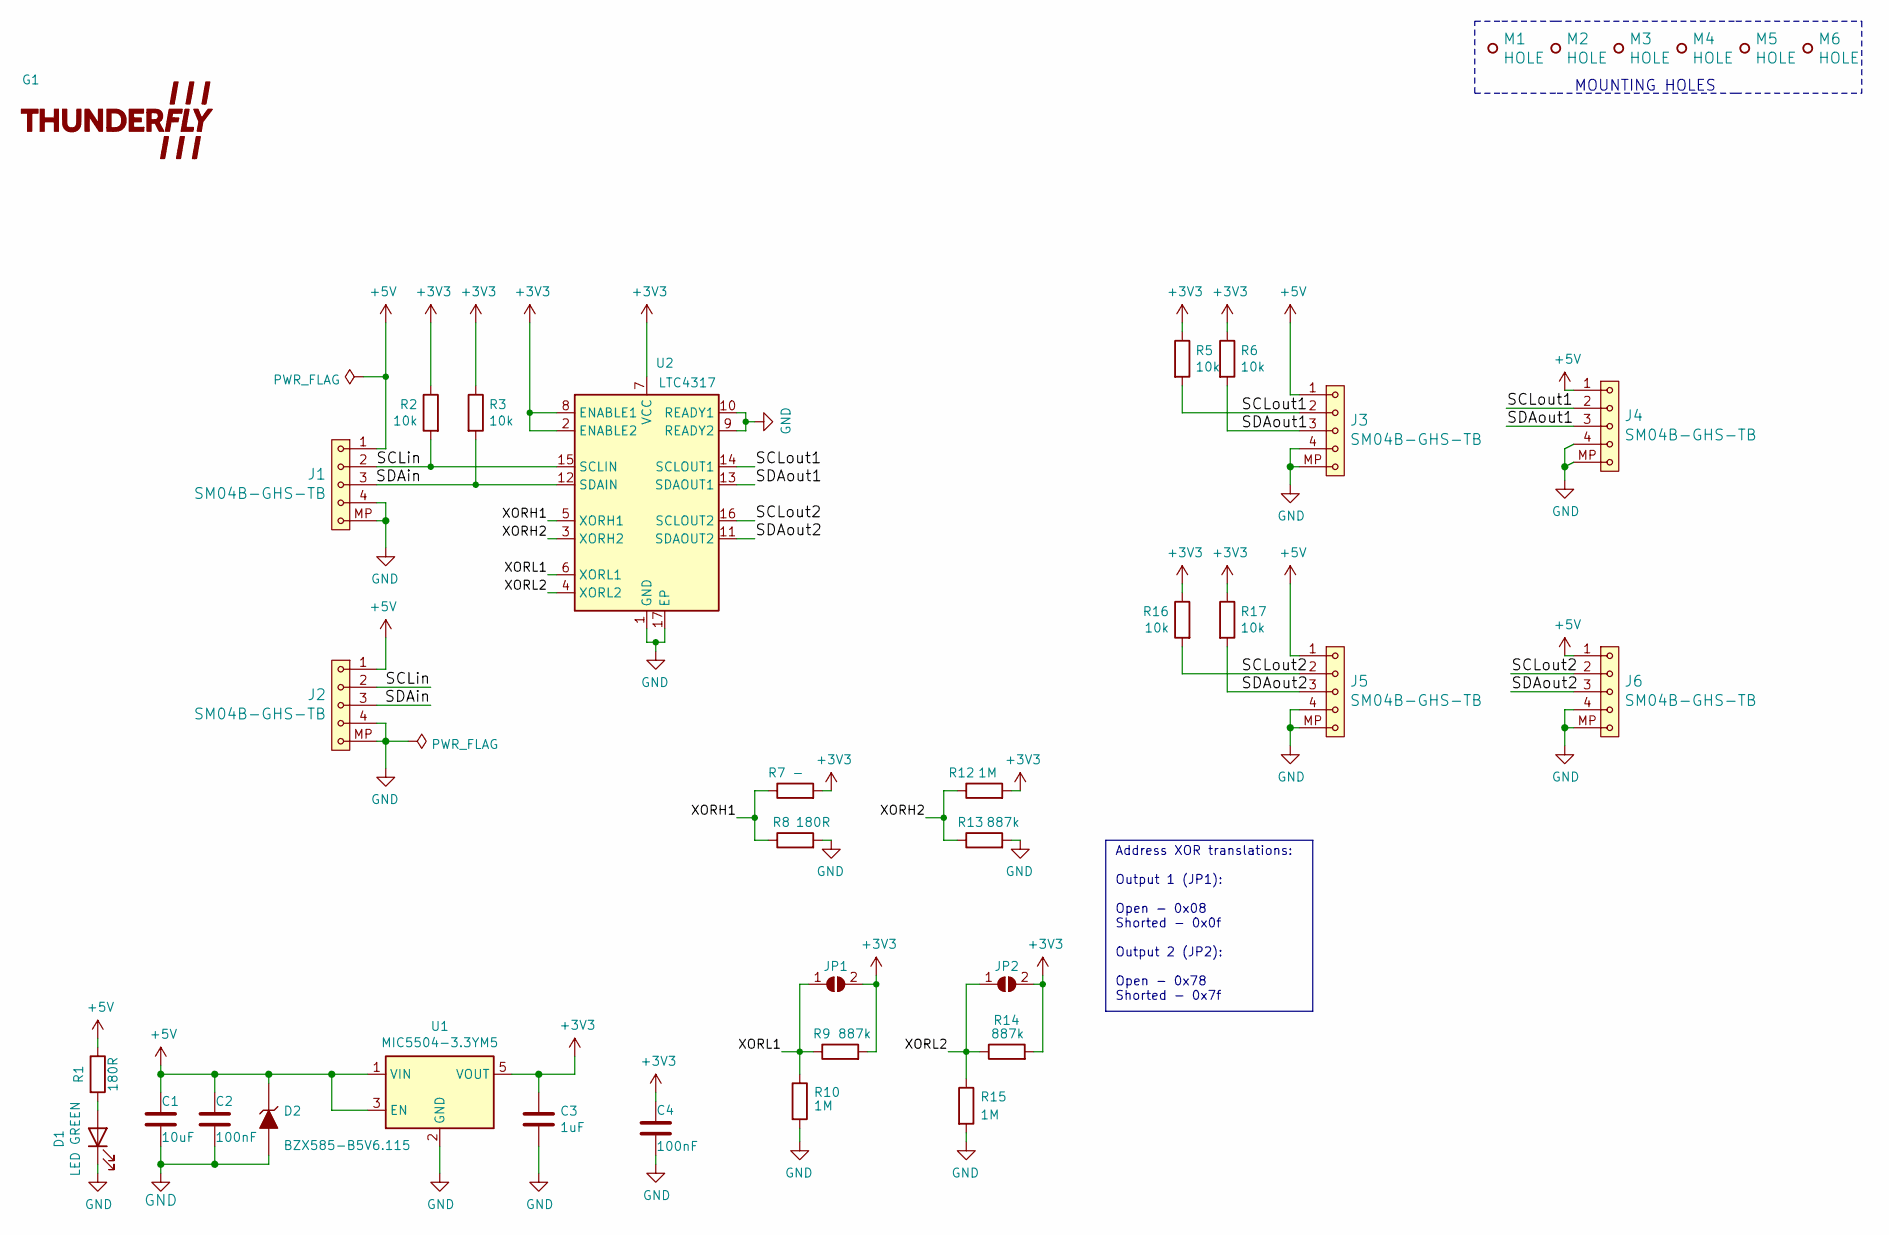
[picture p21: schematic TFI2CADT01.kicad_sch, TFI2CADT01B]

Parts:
C1: 10uF; C_0805_2012Metric
C2, C4: 100nF; C_0603_1608Metric
C3: 1uF; C_0603_1608Metric
D1: LED GREEN; LED_0603_1608Metric
D2: BZX585-B5V6.115; D_SOD-523
G1: LOGO; TF 10x4,7
J1, J2, J3, J4, J5, J6: SM04B-GHS-TB; JST_GH_SM04B-GHS-TB_1x04-1MP_P1.25mm_Horizontal
JP1, JP2: SolderJumper_2_Open; SolderJumper-2_P1.3mm_Open_RoundedPad1.0x1.5mm
M1, M2, M3, M4, M5, M6: HOLE; dira_3mm
R1, R8: 180R; R_0603_1608Metric
R2, R3, R5, R6, R16, R17: 10k; R_0603_1608Metric
R7: -; R_0603_1608Metric
R9, R13, R14: 887k; R_0603_1608Metric
R10, R12, R15: 1M; R_0603_1608Metric
U1: MIC5504-3.3YM5; SOT-23-5
U2: LTC4317; DFN-16-1EP_3x5mm_P0.5mm_EP1.66x4.4mm

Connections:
+3V3: C3.1, C4.1, JP1.2 (B), JP2.2 (B), R2.1, R3.1, R5.1, R6.1, R7.2, R9.2, R12.2, R14.2, R16.1, R17.1, U1.5 (VOUT), U2.2 (ENABLE2), U2.7 (VCC), U2.8 (ENABLE1)
+5V: C1.1, C2.1, D2.1 (K), J1.1, J2.1, J3.1, J4.1, J5.1, J6.1, R1.1, U1.1 (VIN), U1.3 (EN)
/SCLin: J1.2, J2.2, R2.2, U2.15 (SCLIN)
/SCLout1: J3.2, J4.2, R5.2, U2.14 (SCLOUT1)
/SCLout2: J5.2, J6.2, R16.2, U2.16 (SCLOUT2)
/SDAin: J1.3, J2.3, R3.2, U2.12 (SDAIN)
/SDAout1: J3.3, J4.3, R6.2, U2.13 (SDAOUT1)
/SDAout2: J5.3, J6.3, R17.2, U2.11 (SDAOUT2)
/XORH1: R7.1, R8.1, U2.5 (XORH1)
/XORH2: R12.1, R13.1, U2.3 (XORH2)
/XORL1: JP1.1 (A), R9.1, R10.1, U2.6 (XORL1)
/XORL2: JP2.1 (A), R14.1, R15.1, U2.4 (XORL2)
GND: C1.2, C2.2, C3.2, C4.2, D1.1 (K), D2.2 (A), J1.4, J1.MP, J2.4, J2.MP, J3.4, J3.MP, J4.4, J4.MP, J5.4, J5.MP, J6.4, J6.MP, R8.2, R10.2, R13.2, R15.2, U1.2 (GND), U2.1 (GND), U2.9 (READY2), U2.10 (READY1), U2.17 (EP)
unnamed: D1.2 (A), R1.2

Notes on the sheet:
Address XOR translations: Output 1 (JP1): Open - 0x08 Shorted - 0x0f Output 2 (JP2): Open - 0x78 Shorted - 0x7f
MOUNTING HOLES

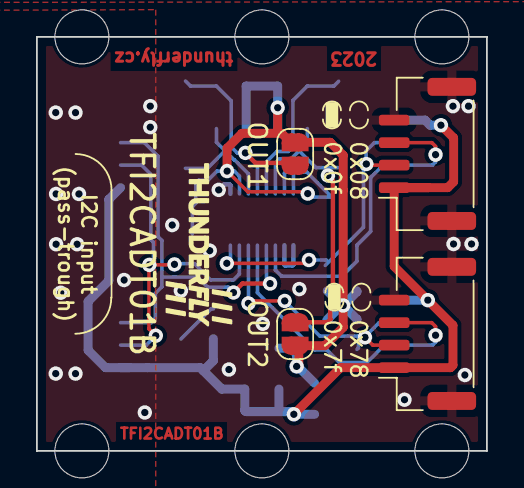
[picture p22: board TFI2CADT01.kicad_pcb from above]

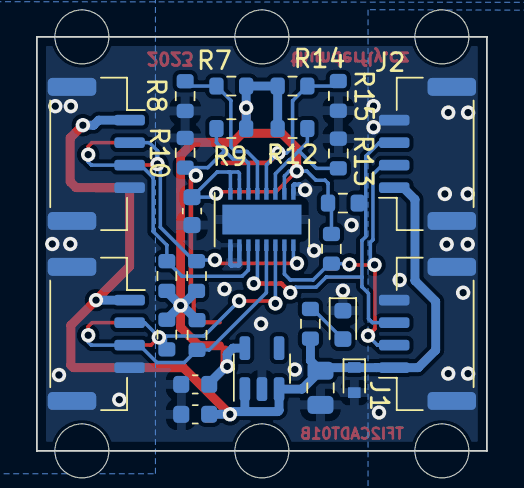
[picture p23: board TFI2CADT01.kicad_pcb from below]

Board: 2 copper layers, 25.0 x 23.0 mm, 38 parts (27 on the bottom side), 14 nets.

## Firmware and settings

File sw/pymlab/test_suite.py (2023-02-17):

import smbus2 as smbus
from IPython.display import Markdown, display

bus = None

def detect():
    d = []
    for device in range(128):
          try:
             bus.read_byte(device)
             #print(hex(device))
             d.append(device)
          except: # exception if read_byte fails
             pass
    return d

def run_test(smbus_port = 0):
    global bus
    bus = smbus.SMBus(smbus_port)
    
    detected = []
    print("Pripojte zarizeni do vstupniho konektoru a stisknete enter")
    input()
    tmp = detect()

    print("Adresa koncoveho I2C zarizeni je: {}".format(hex(tmp[0])))
    detected.append(tmp[0])

    print("Zapojte zarizeni do prekladaneho vystupu a stisknete enter")
    input("")
    tmp = detect()
    print("Nova I2C adresa je: {}".format(hex(tmp[0])))
    detected.append(tmp[0])

    print("Zapojte zarizeni do druheho prekladaneho vystupu a stisknete enter")
    input("")

    tmp = detect()
    print("Nova I2C adresa je: {}".format(hex(tmp[0])))
    detected.append(tmp[0])

    obtained_translate = set( (detected[0]^detected[1], detected[0]^detected[2]) )

    default_translation = {0x8, 0x78}
    if (default_translation == obtained_translate):
        print("")
        print("Preklad adres funguje dle ocekavani")
    else:
        print(" ")
        print("NEFUNGUJE: Preklad adres nefunguje dle ocekavani.")
        print("Výchozí XOR je {} a {}".format(hex(list(default_translation)[0]), hex(list(default_translation)[1])))
        print("")
        print("Predpoklad:")
        print("{}^{} = {}".format(hex(detected[0]), hex(list(default_translation)[0]), hex(detected[0]^list(default_translation)[0])))
        print("{}^{} = {}".format(hex(detected[0]), hex(list(default_translation)[1]), hex(detected[0]^list(default_translation)[1])))
        print("")
        print("Detekovano:")
        print("{}^{} = {}".format(hex(detected[0]), hex(detected[0]^detected[1]), hex(detected[1])))
        print("{}^{} = {}".format(hex(detected[0]), hex(detected[0]^detected[2]), hex(detected[2])))
        print("")
        print("Zkontrolujte, ze jste pripojeni i2c zarizeni provedli ve sravnem poradi")

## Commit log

2022-01-10 Edit schema
    [TFI2CADT01A.csv, TFI2CADT01A.kicad_pcb, TFI2CADT01A.kicad_sch]
2022-01-11 volba adres rezistory
    [TFI2CADT01A.kicad_sch]
2022-01-11 anotace soucastek
    [TFI2CADT01A.kicad_sch]
2022-01-12 Edit PCB
    [TFI2CADT01A.kicad_pcb, TFI2CADT01A.kicad_sch]
2022-01-12 uprava popisu
    [TFI2CADT01A.kicad_pcb]
2022-01-12 oprava teplotnich profilu
    [TFI2CADT01A.kicad_pcb]
2022-01-12 uprava routingu
    [TFI2CADT01A.kicad_pcb, TFI2CADT01A.kicad_sch]
2022-02-02 kompatibilita s verzi 6
    [TFI2CADT01A.kicad_pcb, TFI2CADT01A.kicad_sch]
2022-03-15 update layout
    [TFI2CADT01A.kicad_sch]
2022-03-15 uprava schema, sablona
    [TFI2CADT01A.kicad_sch]
2022-03-24 Update Titleblock Move PCB to center of the page Move grid origin to the bottom left corner of the PCB
    [TFI2CADT01A.kicad_pcb, TFI2CADT01A.kicad_sch]
2022-03-24 Update assets submodule Update KiCAD workflow
2022-03-24 Resolve ERC issues by adding power flags and updating symbols. Update PCB from schematics.
    [TFI2CADT01A.kicad_pcb, TFI2CADT01A.kicad_sch]
2022-03-29 Push actions product
    [TFI2CADT01A-B_Cu.gbr, TFI2CADT01A-B_Mask.gbr, TFI2CADT01A-B_Silkscreen.gbr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]
2022-03-29 uprava pro actions
    [TFI2CADT01A.kicad_pcb, TFI2CADT01A.kicad_sch]
2022-03-29 Uprava symbolu
    [TFI2CADT01A.kicad_sch]
2022-03-30 Update actions products
    [TFI2CADT01A-B_Cu.gbr, TFI2CADT01A-B_Mask.gbr, TFI2CADT01A-B_Paste.gbr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]
2022-04-04 Add ERC exclusion to open collector pins.
    [TFI2CADT01A.kicad_sch]
2023-05-27 save in kicad6
    [TFI2CADT01.kicad_pcb, TFI2CADT01.kicad_sch]
2023-08-09 Update README.md
    Link to other I2C deices.
2023-09-27 Upravy pred vyrobou
    [TFI2CADT01.kicad_pcb]
2023-09-27 Edit kicad_outputs.yml
2023-10-02 Edit UST_ID
    [TFI2CADT01.kicad_sch]
2024-02-12 Aktualizace metadat
    [TFI2CADT01.kicad_pcb, TFI2CADT01.kicad_sch]
2024-02-13 Improve schematics layout run DRC check.
    [TFI2CADT01.kicad_pcb, TFI2CADT01.kicad_sch]
2024-02-13 Update readme and update submodule to kicadv7
2024-02-14 Improve schematics layout.
    [TFI2CADT01.kicad_sch]
2025-09-26 Update project to KiCADv9.
    [TFI2CADT01.kicad_pcb, TFI2CADT01.kicad_sch]
2025-09-26 Fix title box content.
    [TFI2CADT01.kicad_pcb]
